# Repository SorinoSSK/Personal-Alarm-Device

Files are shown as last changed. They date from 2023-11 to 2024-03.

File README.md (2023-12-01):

# Introduction
This repository serves as a record and learning journey on hardware used for my capstone project. The objective of the project is to implement a small, affordable and unrestrictive IoT deviced that enables individuals to call for help in an emergency.

## PCB_Design_GSM_GPS
With the failure to find an appropriate module that carries both the functionality of GPS and GSM, I have decided to design a customised module using [SIM868](https://www.alibaba.com/product-detail/SIM868-Signal-Circuits-GSM-GPS-GNSS_1600272320629.html). SIM868 enables both GSM and GPS communication that is inline with the frequency band used in Singapore, however SIM868 is built for 2G communication and 2G communication is no longer used in Singapore. 

***Update: SIM868 is mostly no longer in production.***\
***SIM868 could not detect 3G or 4G network***

## Schematic_1
Upon searching for SIM868, I stumble across the module A9G and thus drew the schematic to be used for feasibility testing of our idea. A9G also uses GPRS protocol which still runs mostly on a [2G network](https://tinyurl.com/mwhuy22j). 

***Update: A9G could not detect 3G or 4G network***

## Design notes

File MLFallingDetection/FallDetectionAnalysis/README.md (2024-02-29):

# The analysis of falling data of accelerometer
Data are collected from the IMU, **LSM6DS3TR-C** installed within seeed XIAO nRf52840. The sum of square equation will be used on the 3 axis acceleration to obtain the resultant acceleration vector for the analysis. 

```
Norm = SQRT(ACCEL_X**2 + ACCEL_Y**2 + ACCEL_Z**2);
```

## Overview of data retrieved
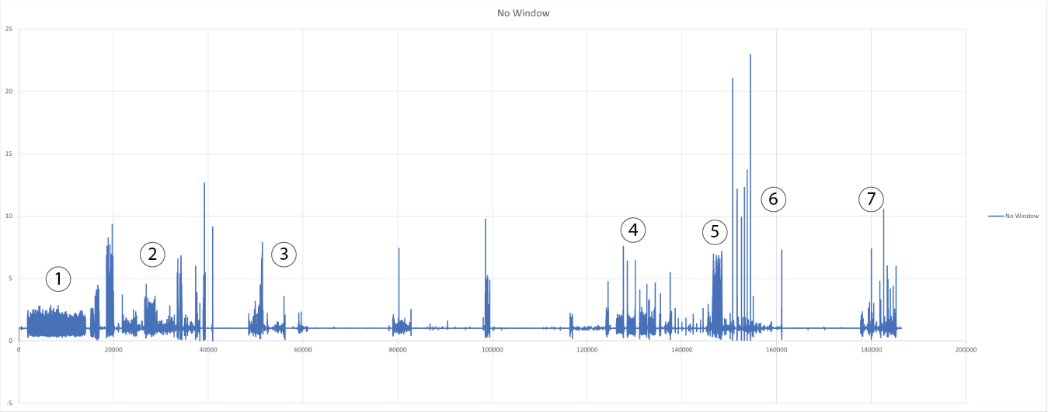
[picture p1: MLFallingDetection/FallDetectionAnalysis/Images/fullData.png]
Falling Data Full

**Legend**
1) Walking
2) Walking Up and Down Stairs
3) Dropping of IMU
4) Sitting and Standing up from plastic chair
5) Shaking of IMU
6) Falling from the chair
7) Fall forward

**Note**
1) The device designed to be used as a keychain, thus the device is placed in the back pocket of our pants during data collection.
2) The shaking of IMU is recorded with it held on the hand.

With that we will include the rate of change in acceleration, the second derivative in the rate of change in acceleration, and moving average of a window of 50 data point,

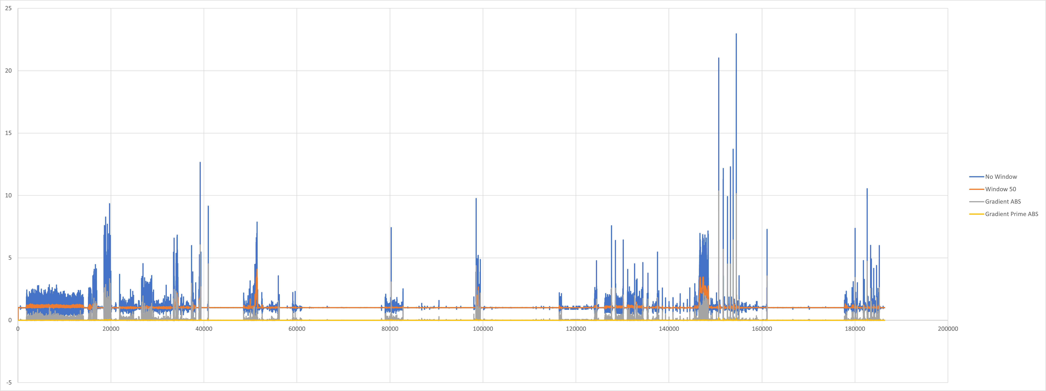
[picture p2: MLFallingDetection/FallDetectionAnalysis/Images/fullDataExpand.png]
Falling Data Full Expand


A few highest rate of change of acceleration will be recorded for analysis.

## Analysing **Walking**
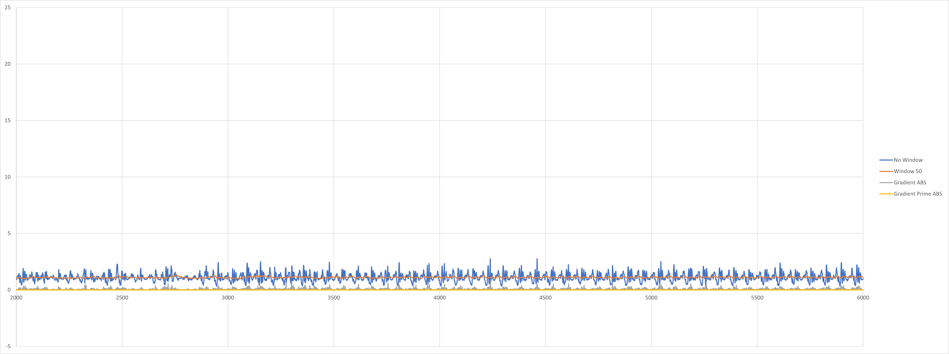
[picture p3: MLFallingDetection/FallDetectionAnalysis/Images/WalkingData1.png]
Walking Data 1

**Zooming in:**\
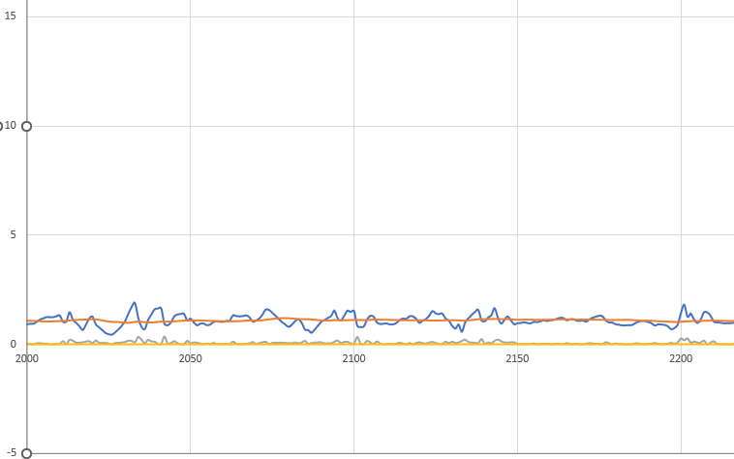
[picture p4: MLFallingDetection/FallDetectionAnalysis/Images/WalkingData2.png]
Walking Data 2

**Note**
1) Random points:

|point| Norm | f'(x) | f''(x) |
|-----|---|---|---|
|2101| 0.85 | 0.336068328 | 0.00305213  |
|2202| 1.25876924  | 0.271906121 | 0.003399633 |
|2325| 1.393448959 | 0.397809776 | 0.003501889 |

## Analysing **Stairs**
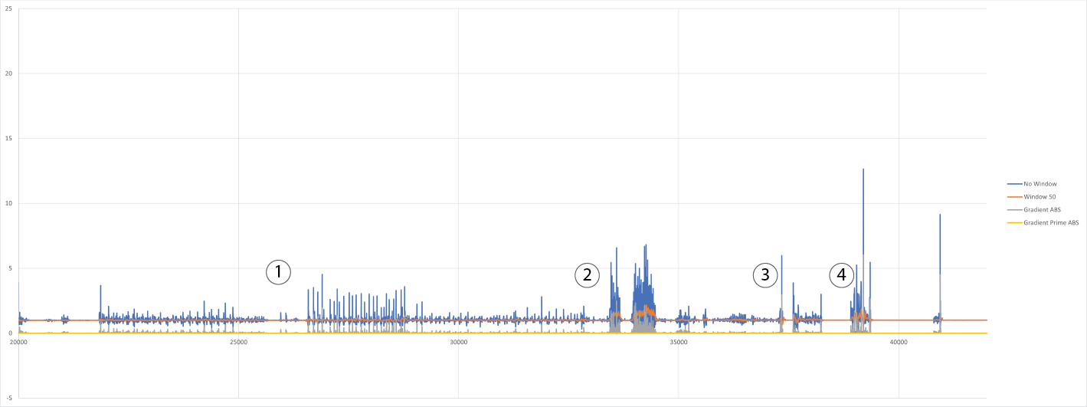
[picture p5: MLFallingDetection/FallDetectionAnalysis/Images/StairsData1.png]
Stairs Data 1

From the graph we could observe two different section where the norm acceleration for going up the stairs is way lower than going down the stairs. Thus, we will analyse the going down of stairs instead. 
**Legend**
1) Walking up then down the stairs
2) Limping up then down the stairs
3) Limping up then down the stairs (Other Leg)
4) Running up then down the stairs

### Walking up then down the stairs
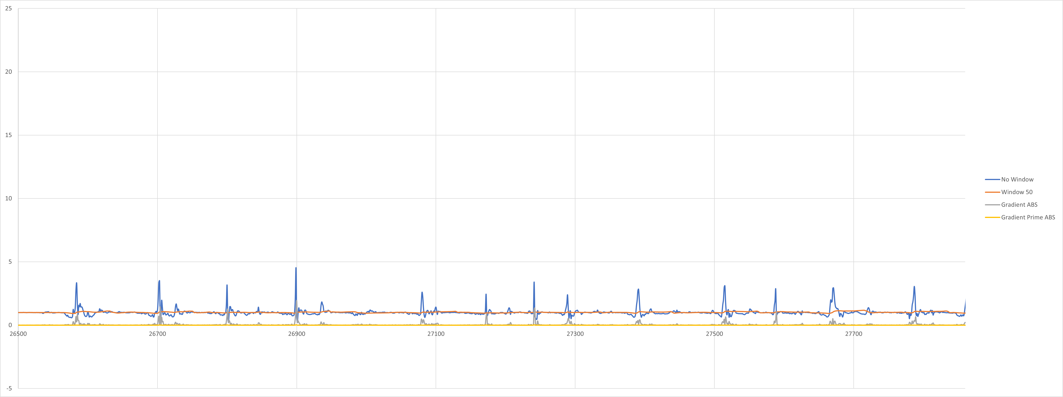
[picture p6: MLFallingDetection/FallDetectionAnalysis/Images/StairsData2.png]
Stairs Data 2

**Note**
|point| Norm | f'(x) | f''(x) |
|-----|---|---|---|
|26704| 0.595399026 | 1.453343034 | 0.015052862 |
|26900| 0.672978454 | 1.922880154 | 0.017114909 |
|27242| 0.904488806 | 0.175432193 | 0.00063385  |

### Limping up and then down the stairs
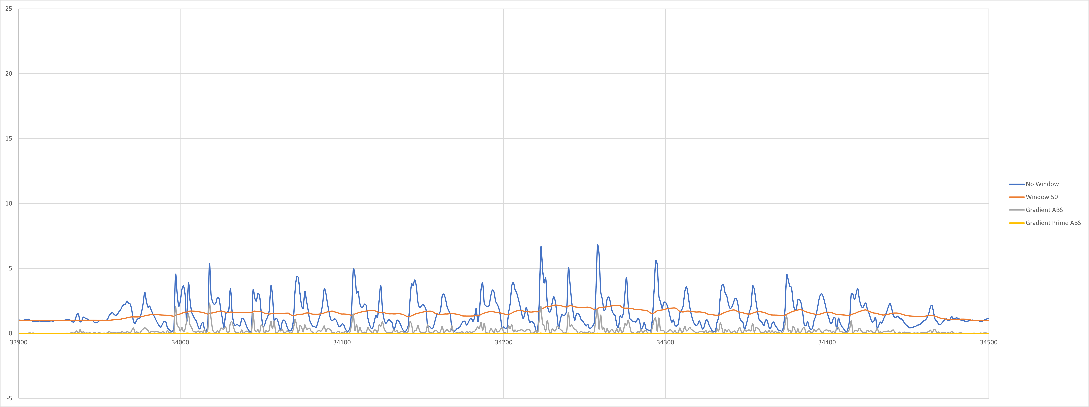
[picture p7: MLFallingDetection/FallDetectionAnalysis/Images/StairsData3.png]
Stairs Data 3

**Note**
|point| Norm | f'(x) | f''(x) |
|-----|---|---|---|
|34018| 5.320620265 | 2.319318931 | 0.034806461 |
|34223| 6.612503308 | 2.080303042 | 0.028609112 |
|34375| 4.503987123 | 1.345020579 | 0.015369838 |

### Limping up and then down the stairs (Other Leg)
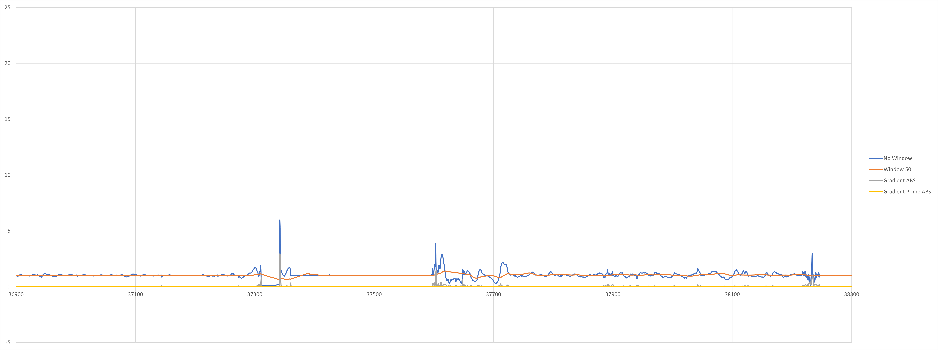
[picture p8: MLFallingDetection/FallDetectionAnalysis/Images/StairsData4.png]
Stairs Data 4

**Note**
|point| Norm | f'(x) | f''(x) |
|-----|---|---|---|
|37342| 5.97850316 | 2.89438325 | 0.05089264  |
|37604| 1.0177426  | 1.427956 | 0.014744675 |
|38234| 3.00627677 | 0.90062282 | 0.019383044 |

**Most Significant Detection**
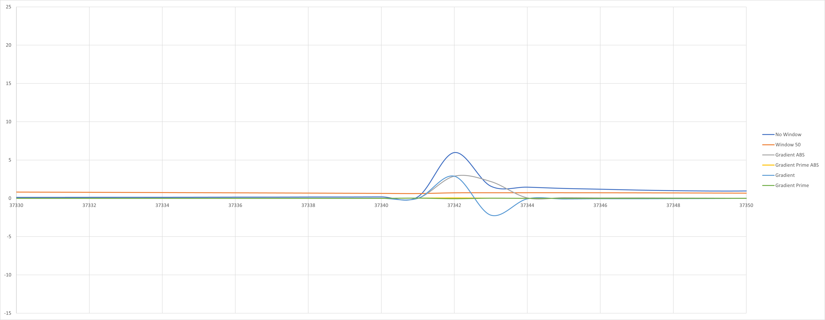
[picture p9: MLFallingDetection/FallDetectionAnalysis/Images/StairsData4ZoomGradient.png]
Stairs Data 4 Zoom


Gradient:  
Max = 2.894383249  
Min = -2.194880759  
*Max Gradient More Than 50 Mean, 0.720361147*

### Running up and then down the stairs
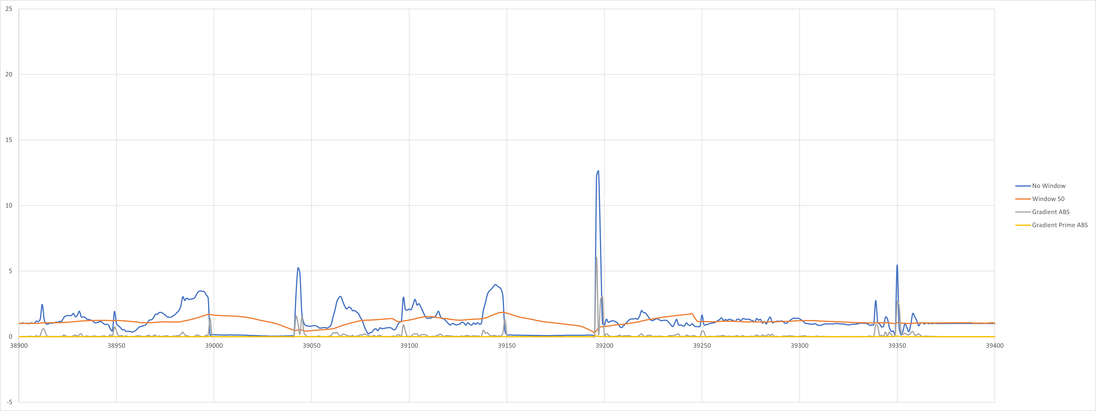
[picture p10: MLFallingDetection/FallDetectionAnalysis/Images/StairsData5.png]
Stairs Data 5

**Note**
|point| Norm | f'(x) | f''(x) |
|-----|---|---|---|
|39196| 12.2078213 | 6.03987939 | 0.058243241 |
|39199| 1.4169686  | 0.01073792 | 0.000376615 |
|39350| 5.46485133 | 2.64582312 | 0.050280346 |

**Most Significant Detection**
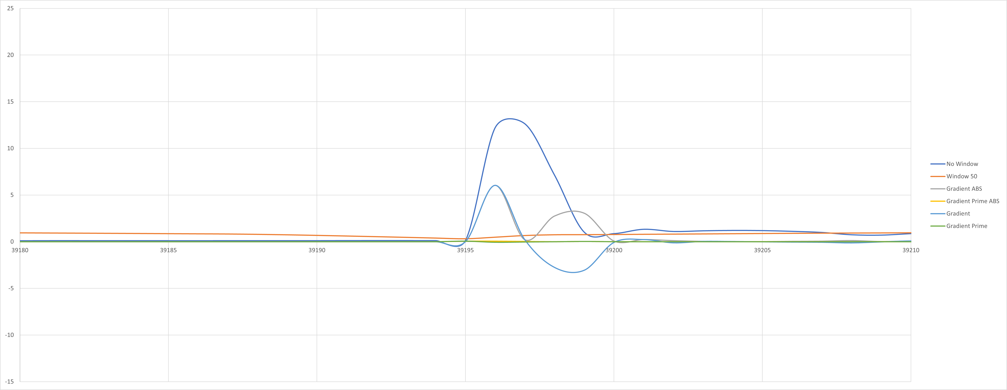
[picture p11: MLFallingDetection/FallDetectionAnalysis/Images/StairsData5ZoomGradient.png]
Stairs Data 5 Zoom


Gradient:  
Max = 1.713900863  
Min = -1.406512019  
*Max Gradient More Than 50 Mean, 0.485567491*

### Dropping of IMU
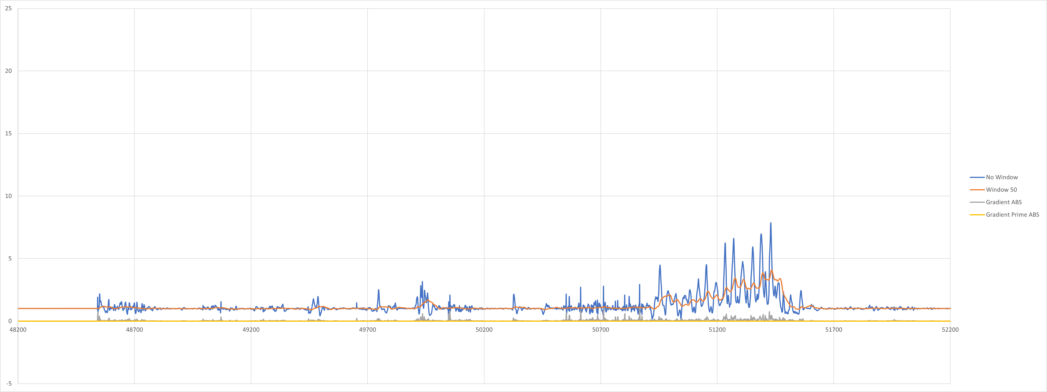
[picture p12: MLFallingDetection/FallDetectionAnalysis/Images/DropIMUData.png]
Drop IMU

**Note**
|point| Norm | f'(x) | f''(x) |
|-----|---|---|---|
|50867| 2.93165482 | 0.84010783 | 0.018871274 |
|51271| 6.60540688 | 0.07334979 | 0.003136808 |
|51429| 7.66756806 | 0.42955872 | 0.003312123 |

### Sitting and standing from plastic chair
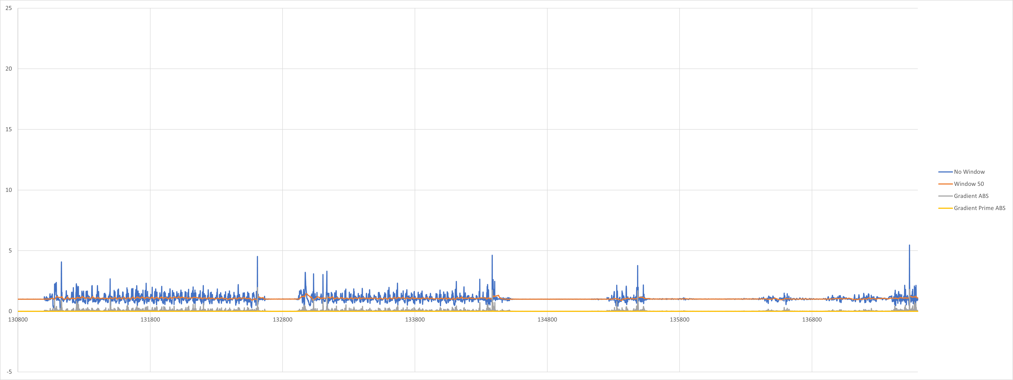
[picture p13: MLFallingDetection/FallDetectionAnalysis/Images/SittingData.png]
Sitting Standing

**Note**
|point| Norm | f'(x) | f''(x) |
|-----|---|---|---|
|124418| 1.3924439  | 1.67057441 | 0.016458247 |
|127650| 7.57681331 | 2.39403404 | 0.04951892  |
|128489| 6.39746043 | 2.56434075 | 0.050413023 |
|128490| 1.44353732 | 2.47696156 | 0.02131954  |

**Most Significant Detection**
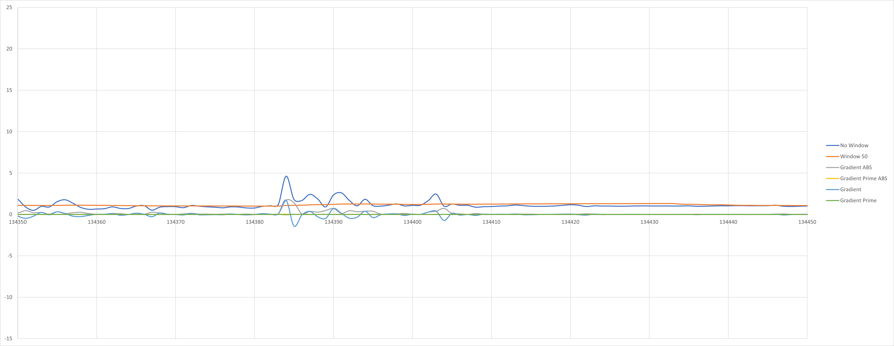
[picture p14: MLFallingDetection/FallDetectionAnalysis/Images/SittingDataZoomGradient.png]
Sitting Standing Zoom


### Shaking of IMU
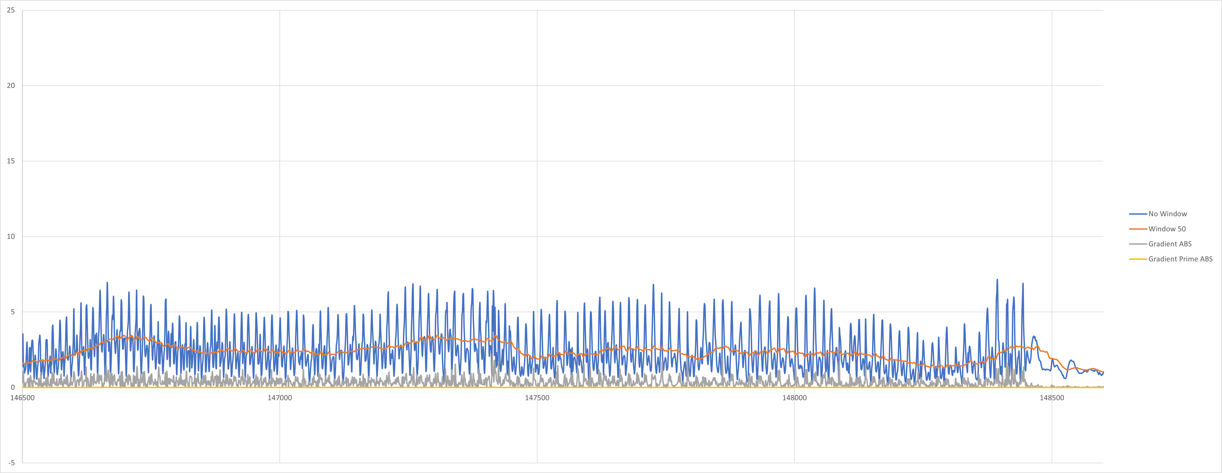
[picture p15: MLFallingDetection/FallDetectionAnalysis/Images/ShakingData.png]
Shaking of IMU

**Note**
|point| Norm | f'(x) | f''(x) |
|-----|---|---|---|
|147413| 5.33691859 | 2.18263525 | 0.02974069 |
|148087| 3.92880389 | 1.74343815 | 0.019434068|
|148412| 5.50270842 | 1.65809075 | 0.018426668|

**Most Significant Detection**
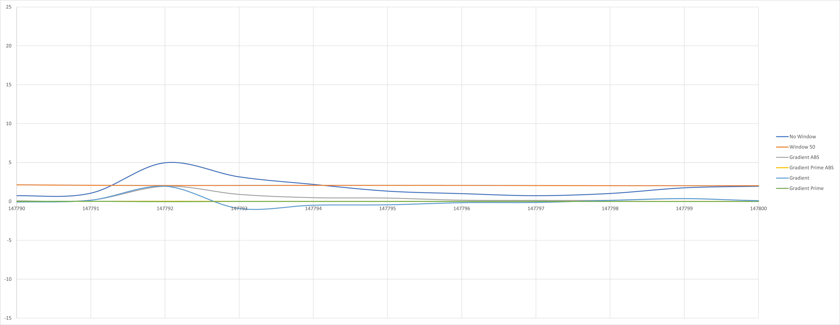
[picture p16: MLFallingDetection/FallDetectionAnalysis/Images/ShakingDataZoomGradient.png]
Shaking IMU Zoom


Gradient:  
Max = 1.713900863  
Min = -1.406512019  
*Max Gradient More Than 50 Mean, 1.084352*

### Falling
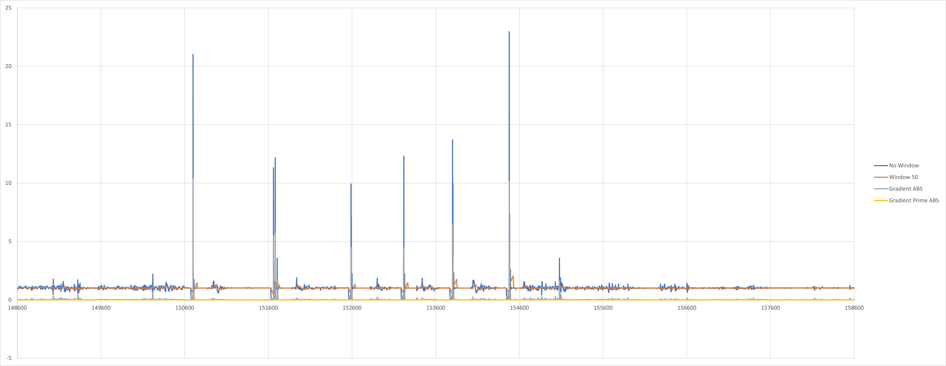
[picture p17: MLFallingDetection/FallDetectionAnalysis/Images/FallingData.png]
Falling

**Note**
|point| Norm | f'(x) | f''(x) |
|-----|---|---|---|
|150700| 21.0203187 | 10.2686019 | 0.19819152 |
|151661| 11.0312737 | 5.46538749 | 0.07213993 |
|151682| 12.1636426 | 5.63318495 | 0.108593481|
|152588| 9.91117047 | 4.42504366 | 0.082039699|
|153219| 12.2903051 | 3.57987967 | 0.080156318|
|153220| 3.41880096 | 4.43575208 | 0.037172477|
|153801| 13.5009852 | 6.39711601 | 0.090973936|
|154478| 22.5853692 | 10.1236572 | 0.140823507|

**Insignificant Detection**
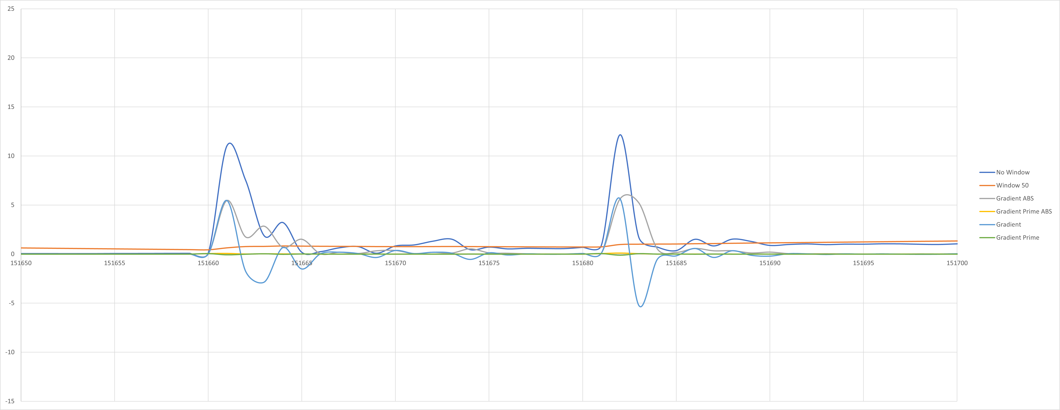
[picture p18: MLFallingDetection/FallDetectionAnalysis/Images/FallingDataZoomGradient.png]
Falling Zoom


Gradient:  
Max = 1.954421754  
Min = -0.48353773  
*Max Gradient Lower than 50 Mean*

### Falling Forward
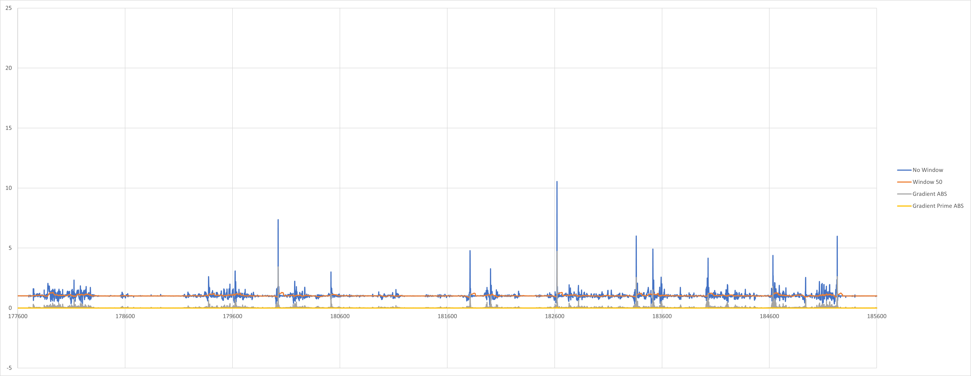
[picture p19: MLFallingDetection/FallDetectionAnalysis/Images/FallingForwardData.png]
Falling Forward

**Note**
|point| Norm | f'(x) | f''(x) |
|-----|---|---|---|
|180025| 7.3281495  | 3.38140316 | 0.053954091|
|181812| 4.75042103 | 1.17818295 | 0.014426057|
|182622| 10.5353643 | 3.69902825 | 0.083047814|
|182623| 1.323858 | 4.60575313 | 0.043626618|
|183360| 5.94348383 | 2.53134437 | 0.037461287|
|183515| 4.87521282 | 1.51486592 | 0.022030153|
|184633| 4.35516934 | 1.79035089 | 0.026907707|
|185232| 5.98194784 | 2.56913272 | 0.046908972|

**Insignificant Detection**
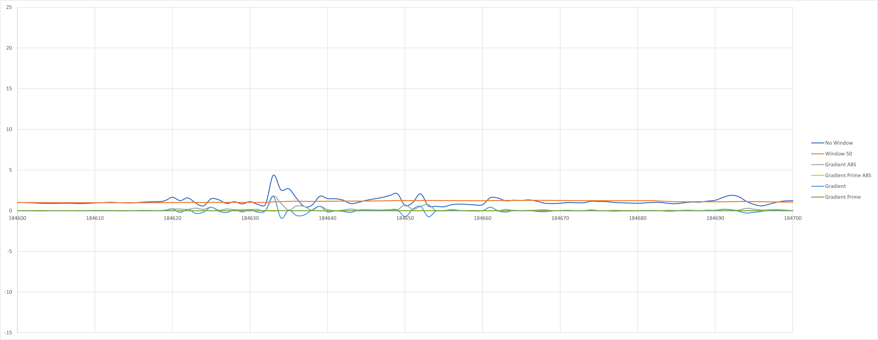
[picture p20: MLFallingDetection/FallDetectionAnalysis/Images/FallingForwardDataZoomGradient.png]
Falling Zoom Forward


### Summaries Data
|Type|point| Norm | f'(x) | f''(x) |
|----|-----|---|---|---|
|1|2101| 0.85 | 0.336068328 | 0.00305213  |
|1|2202| 1.25876924  | 0.271906121 | 0.003399633 |
|1|2325| 1.393448959 | 0.397809776 | 0.003501889 |
|2.1|26704| 0.595399026 | 1.453343034 | 0.015052862 |
|2.1|26900| 0.672978454 | 1.922880154 | 0.017114909 |
|2.1|27242| 0.904488806 | 0.175432193 | 0.00063385  |
|2.2|34018| 5.320620265 | 2.319318931 | 0.034806461 |
|2.2|34223| 6.612503308 | 2.080303042 | 0.028609112 |
|2.2|34375| 4.503987123 | 1.345020579 | 0.015369838 |
|2.3|37342| 5.97850316 | 2.89438325 | 0.05089264  |
|2.3|37604| 1.0177426  | 1.427956 | 0.014744675 |
|2.3|38234| 3.00627677 | 0.90062282 | 0.019383044 |
|2.4|39196| 12.2078213 | 6.03987939 | 0.058243241 |
|2.4|39199| 1.4169686  | 0.01073792 | 0.000376615 |
|2.4|39350| 5.46485133 | 2.64582312 | 0.050280346 |
|3|50867| 2.93165482 | 0.84010783 | 0.018871274 |
|3|51271| 6.60540688 | 0.07334979 | 0.003136808 |
|3|51429| 7.66756806 | 0.42955872 | 0.003312123 |
|4|124418| 1.3924439  | 1.67057441 | 0.016458247 |
|4|127650| 7.57681331 | 2.39403404 | 0.04951892  |
|4|128489| 6.39746043 | 2.56434075 | 0.050413023 |
|4|128490| 1.44353732 | 2.47696156 | 0.02131954  |
|5|147413| 5.33691859 | 2.18263525 | 0.02974069 |
|5|148087| 3.92880389 | 1.74343815 | 0.019434068|
|5|148412| 5.50270842 | 1.65809075 | 0.018426668|
|6|150700| 21.0203187 | 10.2686019 | 0.19819152 |
|6|151661| 11.0312737 | 5.46538749 | 0.07213993 |
|6|151682| 12.1636426 | 5.63318495 | 0.108593481|
|6|152588| 9.91117047 | 4.42504366 | 0.082039699|
|6|153219| 12.2903051 | 3.57987967 | 0.080156318|
|6|153220| 3.41880096 | 4.43575208 | 0.037172477|
|6|153801| 13.5009852 | 6.39711601 | 0.090973936|
|6|154478| 22.5853692 | 10.1236572 | 0.140823507|
|7|180025| 7.3281495  | 3.38140316 | 0.053954091|
|7|181812| 4.75042103 | 1.17818295 | 0.014426057|
|7|182622| 10.5353643 | 3.69902825 | 0.083047814|
|7|182623| 1.323858 | 4.60575313 | 0.043626618|
|7|183360| 5.94348383 | 2.53134437 | 0.037461287|
|7|183515| 4.87521282 | 1.51486592 | 0.022030153|
|7|184633| 4.35516934 | 1.79035089 | 0.026907707|
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

From the above data we can denote the following

|Non-Falling|Norm|f'(x)|f''(x)|
|---|----|-----|---|
|Min|0.595399026|0.01073792|0.000376615|
|Max|12.2078213|6.03987939|0.058243241|

|Falling|Norm|f'(x)|f''(x)|
|---|----|-----|---|
|Min|1.323858|1.17818295|0.014426057|
|Max|22.5853692|10.2686019|0.19819152|

From the data we can assume the following:
1) If f''(x) is > 0.06, we could say that a fall occur.
2) For f'(x) > 1.178, we will need a second verification.
3) For f(x) > 1.323, we will need a second verificaiton.

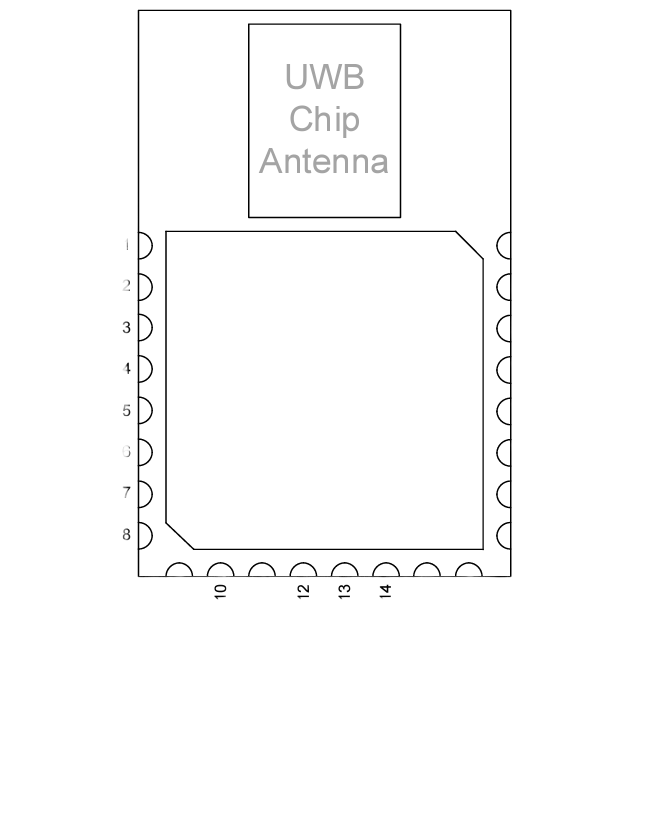
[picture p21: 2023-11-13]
Device Design/Schematic_1/Image/DWM1000_nobg.png

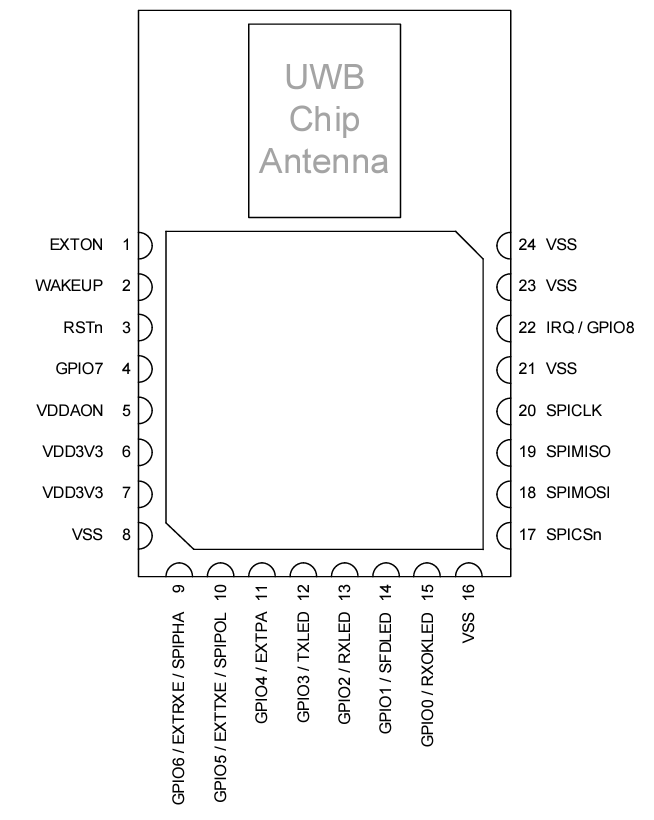
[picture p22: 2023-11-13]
Device Design/Schematic_1/Image/DWM1000.png

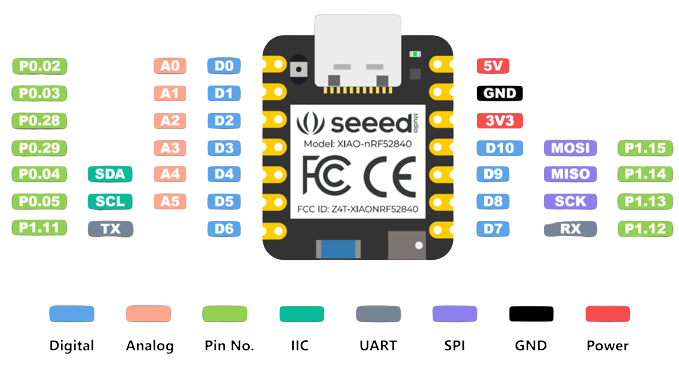
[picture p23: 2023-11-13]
Device Design/Schematic_1/Image/seeed_Xiao_nobg.png

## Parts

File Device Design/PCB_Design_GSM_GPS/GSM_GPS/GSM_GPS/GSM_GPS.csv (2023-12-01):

Source: | D:\[01] Laptop Files\[02] GitFolder\Capstone-2023\PCB_Design_GSM_GPS\GSM_GPS\GSM_GPS.kicad_sch
Date: | 13/11/2023 8:51
Tool: | Eeschema 7.0.8
Generator: | C:\Program Files\KiCad\7.0\bin\scripting\plugins/bom_csv_grouped_by_value.py
Component Count: | 61
Collated Components:
Item | Qty | Reference(s) | Value | LibPart | Footprint | Datasheet | DNP | Availability | Check_prices | Description | MANUFACTURER | MAXIMUM_PACKAGE_HEIGHT | MF | MP | PARTREV | Package | Price | Purchase-URL | STANDARD | SnapEDA_Link
1 | 2 | C1, C4 | 100uF | Device:C_Small | Capacitor_SMD:C_0805_2012Metric | ~
2 | 3 | C2, C3, C14 | 330uF | Device:C_Polarized_Small | Capacitor_SMD:CP_Elec_8x10.5 | ~
3 | 1 | C5 | 33pF | Device:C_Small | Capacitor_SMD:C_0201_0603Metric | ~
4 | 1 | C6 | 10pF | Device:C_Small | Capacitor_SMD:C_0402_1005Metric | ~
5 | 3 | C7, C8, C9 | 22pF | Device:C_Small | Capacitor_SMD:C_0402_1005Metric | ~
6 | 2 | C10, C15 | 0.1uF | Device:C_Small | Capacitor_SMD:C_0201_0603Metric | ~
7 | 1 | C11 | 0.5pF | Device:C_Small | Capacitor_SMD:C_0201_0603Metric | ~
8 | 1 | C12 | 100uF | Device:C_Polarized_Small | Capacitor_SMD:CP_Elec_6.3x5.4 | ~
9 | 1 | C13 | 1uF | Device:C_Small | Capacitor_SMD:C_0201_0603Metric | ~
10 | 2 | D2, D3 | LED | Device:LED | LED_SMD:LED_0201_0603Metric_Pad0.64x0.40mm_HandSolder | ~
11 | 1 | D4 | ESDA6V1-5SC6 | Power_Protection:ESDA6V1-5SC6 | Package_TO_SOT_SMD:SOT-23-6 | www.st.com/resource/en/datasheet/esda6v1-5sc6.pdf
12 | 1 | D5 | 5.1V | Device:D_Zener | Diode_SMD:D_0201_0603Metric | ~
13 | 1 | E1 | YC0003AA | YC0003AA:YC0003AA | YC0003AA:XCVR_YC0003AA |  |  | In Stock | https://www.snapeda.com/parts/YC0003AA/Quectel/view-part/?ref=eda | Frequency band: 698960MHz, 16952200MHz, 23002700MHz; Peak efficiency: 79%; Dimensions: 40mm 7mm 3mm; SMD supplied tape and reel; RoHS and REACH compliant. | Quectel | 3.3mm | Quectel Wireless Solutions Co., Ltd | YC0003AA | 3 | None | None | https://www.snapeda.com/api/url_track_click_mouser/?unipart_id=5161832&manufacturer=Quectel Wireless Solutions Co., Ltd&part_name=YC0003AA&search_term=None | Manufacturer Recommendations | https://www.snapeda.com/parts/YC0003AA/Quectel/view-part/?ref=snap
14 | 1 | E2 | ACAG0301-1575-T | ACAG0301-1575-T:ACAG0301-1575-T | ACAG0301-1575-T:ANT_ACAG0301-1575-T |  |  | In Stock | https://www.snapeda.com/parts/ACAG0301-1575-T/Abracon+LLC/view-part/?ref=eda | MULTIBAND GNSS CHIP ANT SMD | Abracon LLC | 0.7 mm | Abracon LLC | ACAG0301-1575-T | 06.21.2018 | SMD Abracon LLC | None | https://www.snapeda.com/api/url_track_click_mouser/?unipart_id=3077605&manufacturer=Abracon LLC&part_name=ACAG0301-1575-T&search_term=None | Manufacturer Recommendations | https://www.snapeda.com/parts/ACAG0301-1575-T/Abracon+LLC/view-part/?ref=snap
15 | 1 | J1 | SIM8051-6-0-14-00-X-REVD | SIM8051-6-0-14-00-X-REVD:SIM8051-6-0-14-00-X-REVD | SIM8051-6-0-14-00-X-REVD:GCT_SIM8051-6-0-14-00-X-REVD |  |  | In Stock | https://www.snapeda.com/parts/SIM8051-6-0-14-00-A/Global+Connector+Technology/view-part/?ref=eda | 6 Position Card Connector NANO SIM Surface Mount, Right Angle Gold | GCT |  | Global Connector Technology | SIM8051-6-0-14-00-A |  | None | None |  |  | https://www.snapeda.com/parts/SIM8051-6-0-14-00-A/Global+Connector+Technology/view-part/?ref=snap
16 | 8 | J2, J3, J5, J6, J8, J9, J10, J11 | Conn_01x03_Pin | Connector:Conn_01x03_Pin | Connector_Molex:Molex_SPOX_5267-03A_1x03_P2.50mm_Vertical | ~
17 | 9 | J4, J12, J13, J14, J15, J16, J17, J18, J19 | Conn_01x04_Pin | Connector:Conn_01x04_Pin | Connector_Molex:Molex_SPOX_5267-04A_1x04_P2.50mm_Vertical | ~
18 | 3 | J7, J20, J21 | Conn_01x02_Pin | Connector:Conn_01x02_Pin | Connector_Molex:Molex_SPOX_5267-02A_1x02_P2.50mm_Vertical | ~
19 | 1 | L1 | 3.3nH | Device:L | Inductor_SMD:L_0402_1005Metric | ~
20 | 1 | L2 | 6.8nH | Device:L | Inductor_SMD:L_0201_0603Metric | ~
21 | 1 | L3 | 2.4nH | Device:L | Inductor_SMD:L_0402_1005Metric | ~
22 | 1 | L4 | 5.6nH | Device:L | Inductor_SMD:L_0201_0603Metric | ~
23 | 1 | Q1 | 2N3904 | Transistor_BJT:2N3904 | Package_TO_SOT_THT:TO-92_Inline | https://www.onsemi.com/pub/Collateral/2N3903-D.PDF
24 | 3 | R1, R2, R3 | 22 | Device:R | Resistor_SMD:R_0201_0603Metric | ~
25 | 4 | R4, R5, R6, R7 | 4.7k | Device:R | Resistor_SMD:R_0201_0603Metric | ~
26 | 1 | R8 | 10k | Device:R | Resistor_SMD:R_0201_0603Metric | ~
27 | 1 | R9 | 100k | Device:R | Resistor_SMD:R_0201_0603Metric | ~
28 | 1 | R10 | 43k | Device:R | Resistor_SMD:R_0805_2012Metric | ~
29 | 1 | R11 | 470k | Device:R | Resistor_SMD:R_0201_0603Metric | ~
30 | 1 | U1 | SIM868 | SIM868:SIM868 | SIM868:XCVR_SIM868 |  |  | Not in stock | https://www.snapeda.com/parts/SIM868/MikroElektronika/view-part/?ref=eda | SIM868 GNSS, GSM RF mikroBUS™ Click™ Platform Evaluation Expansion Board | SimCom |  | MikroElektronika | SIM868 |  | None | None |  |  | https://www.snapeda.com/parts/SIM868/MikroElektronika/view-part/?ref=snap
31 | 1 | U2 | SeeeduinoXIAO nRF52840 Sense | Seeeduino XIAO:SeeeduinoXIAO | Seeed Studio XIAO Series Library:XIAO-nRF52840-Sense-14P-2.54-21X17.8MM
32 | 1 | U3 | MIC29302AWD | Regulator_Linear:MIC29302AWD | Package_TO_SOT_SMD:TO-252-5_TabPin3 | https://ww1.microchip.com/downloads/aemDocuments/documents/OTH/ProductDocuments/DataSheets/20005897B.pdf

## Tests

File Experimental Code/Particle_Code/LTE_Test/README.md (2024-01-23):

# LTE_Test

This firmware project was created using [Particle Developer Tools](https://www.particle.io/developer-tools/) and is compatible with all [Particle Devices](https://www.particle.io/devices/).

Feel free to replace this README.md file with your own content, or keep it for reference.

## Table of Contents
- [Introduction](#introduction)
- [Prerequisites To Use This Template](#prerequisites-to-use-this-repository)
- [Getting Started](#getting-started)
- [Particle Firmware At A Glance](#particle-firmware-at-a-glance)
  - [Logging](#logging)
  - [Setup and Loop](#setup-and-loop)
  - [Delays and Timing](#delays-and-timing)
  - [Testing and Debugging](#testing-and-debugging)
  - [GitHub Actions (CI/CD)](#github-actions-cicd)
  - [OTA](#ota)
- [Support and Feedback](#support-and-feedback)
- [Version](#version)

## Introduction

For an in-depth understanding of this project template, please refer to our [documentation](https://docs.particle.io/firmware/best-practices/firmware-template/).

## Prerequisites To Use This Repository

To use this software/firmware on a device, you'll need:

- A [Particle Device](https://www.particle.io/devices/).
- Windows/Mac/Linux for building the software and flashing it to a device.
- [Particle Development Tools](https://docs.particle.io/getting-started/developer-tools/developer-tools/) installed and set up on your computer.
- Optionally, a nice cup of tea (and perhaps a biscuit).

## Getting Started

1. While not essential, we recommend running the [device setup process](https://setup.particle.io/) on your Particle device first. This ensures your device's firmware is up-to-date and you have a solid baseline to start from.

2. If you haven't already, open this project in Visual Studio Code (File -> Open Folder). Then [compile and flash](https://docs.particle.io/getting-started/developer-tools/workbench/#cloud-build-and-flash) your device. Ensure your device's USB port is connected to your computer.

3. Verify the device's operation by monitoring its logging output:
    - In Visual Studio Code with the Particle Plugin, open the [command palette](https://docs.particle.io/getting-started/developer-tools/workbench/#particle-commands) and choose "Particle: Serial Monitor".
    - Or, using the Particle CLI, execute:
    ```
    particle serial monitor --follow
    ```

4. Uncomment the code at the bottom of the cpp file in your src directory to publish to the Particle Cloud! Login to console.particle.io to view your devices events in real time.

5. Customize this project! For firmware details, see [Particle firmware](https://docs.particle.io/reference/device-os/api/introduction/getting-started/). For information on the project's directory structure, visit [this link](https://docs.particle.io/firmware/best-practices/firmware-template/#project-overview).

## Particle Firmware At A Glance

### Logging

The firmware includes a [logging library](https://docs.particle.io/reference/device-os/api/logging/logger-class/). You can display messages at different levels and filter them:

```
Log.trace("This is trace message");
Log.info("This is info message");
Log.warn("This is warn message");
Log.error("This is error message");
```

### Setup and Loop

Particle projects originate from the Wiring/Processing framework, which is based on C++. Typically, one-time setup functions are placed in `setup()`, and the main application runs from the `loop()` function.

For advanced scenarios, explore our [threading support](https://docs.particle.io/firmware/software-design/threading-explainer/).

### Delays and Timing

By default, the setup() and loop() functions are blocking whilst they run, meaning that if you put in a delay, your entire application will wait for that delay to finish before anything else can run. 

For techniques that allow you to run multiple tasks in parallel without creating threads, checkout the code example [here](https://docs.particle.io/firmware/best-practices/firmware-template/).

(Note: Although using `delay()` isn't recommended for best practices, it's acceptable for testing.)

### Testing and Debugging

For firmware testing and debugging guidance, check [this documentation](https://docs.particle.io/troubleshooting/guides/build-tools-troubleshooting/debugging-firmware-builds/).

### GitHub Actions (CI/CD)

This project provides a YAML file for GitHub, automating firmware compilation whenever changes are pushed. More details on [Particle GitHub Actions](https://docs.particle.io/firmware/best-practices/github-actions/) are available.

### OTA

To learn how to utilize Particle's OTA service for device updates, consult [this documentation](https://docs.particle.io/getting-started/cloud/ota-updates/).

Test OTA with the 'Particle: Cloud Flash' command in Visual Studio Code or the CLI command 'particle flash'!

This firmware supports binary assets in OTA packages, allowing the inclusion of audio, images, configurations, and external microcontroller firmware. More details are [here](https://docs.particle.io/reference/device-os/api/asset-ota/asset-ota/).

## Support and Feedback

For support or feedback on this template or any Particle products, please join our [community](https://community.particle.io)!

## Version

Template version 1.0.2

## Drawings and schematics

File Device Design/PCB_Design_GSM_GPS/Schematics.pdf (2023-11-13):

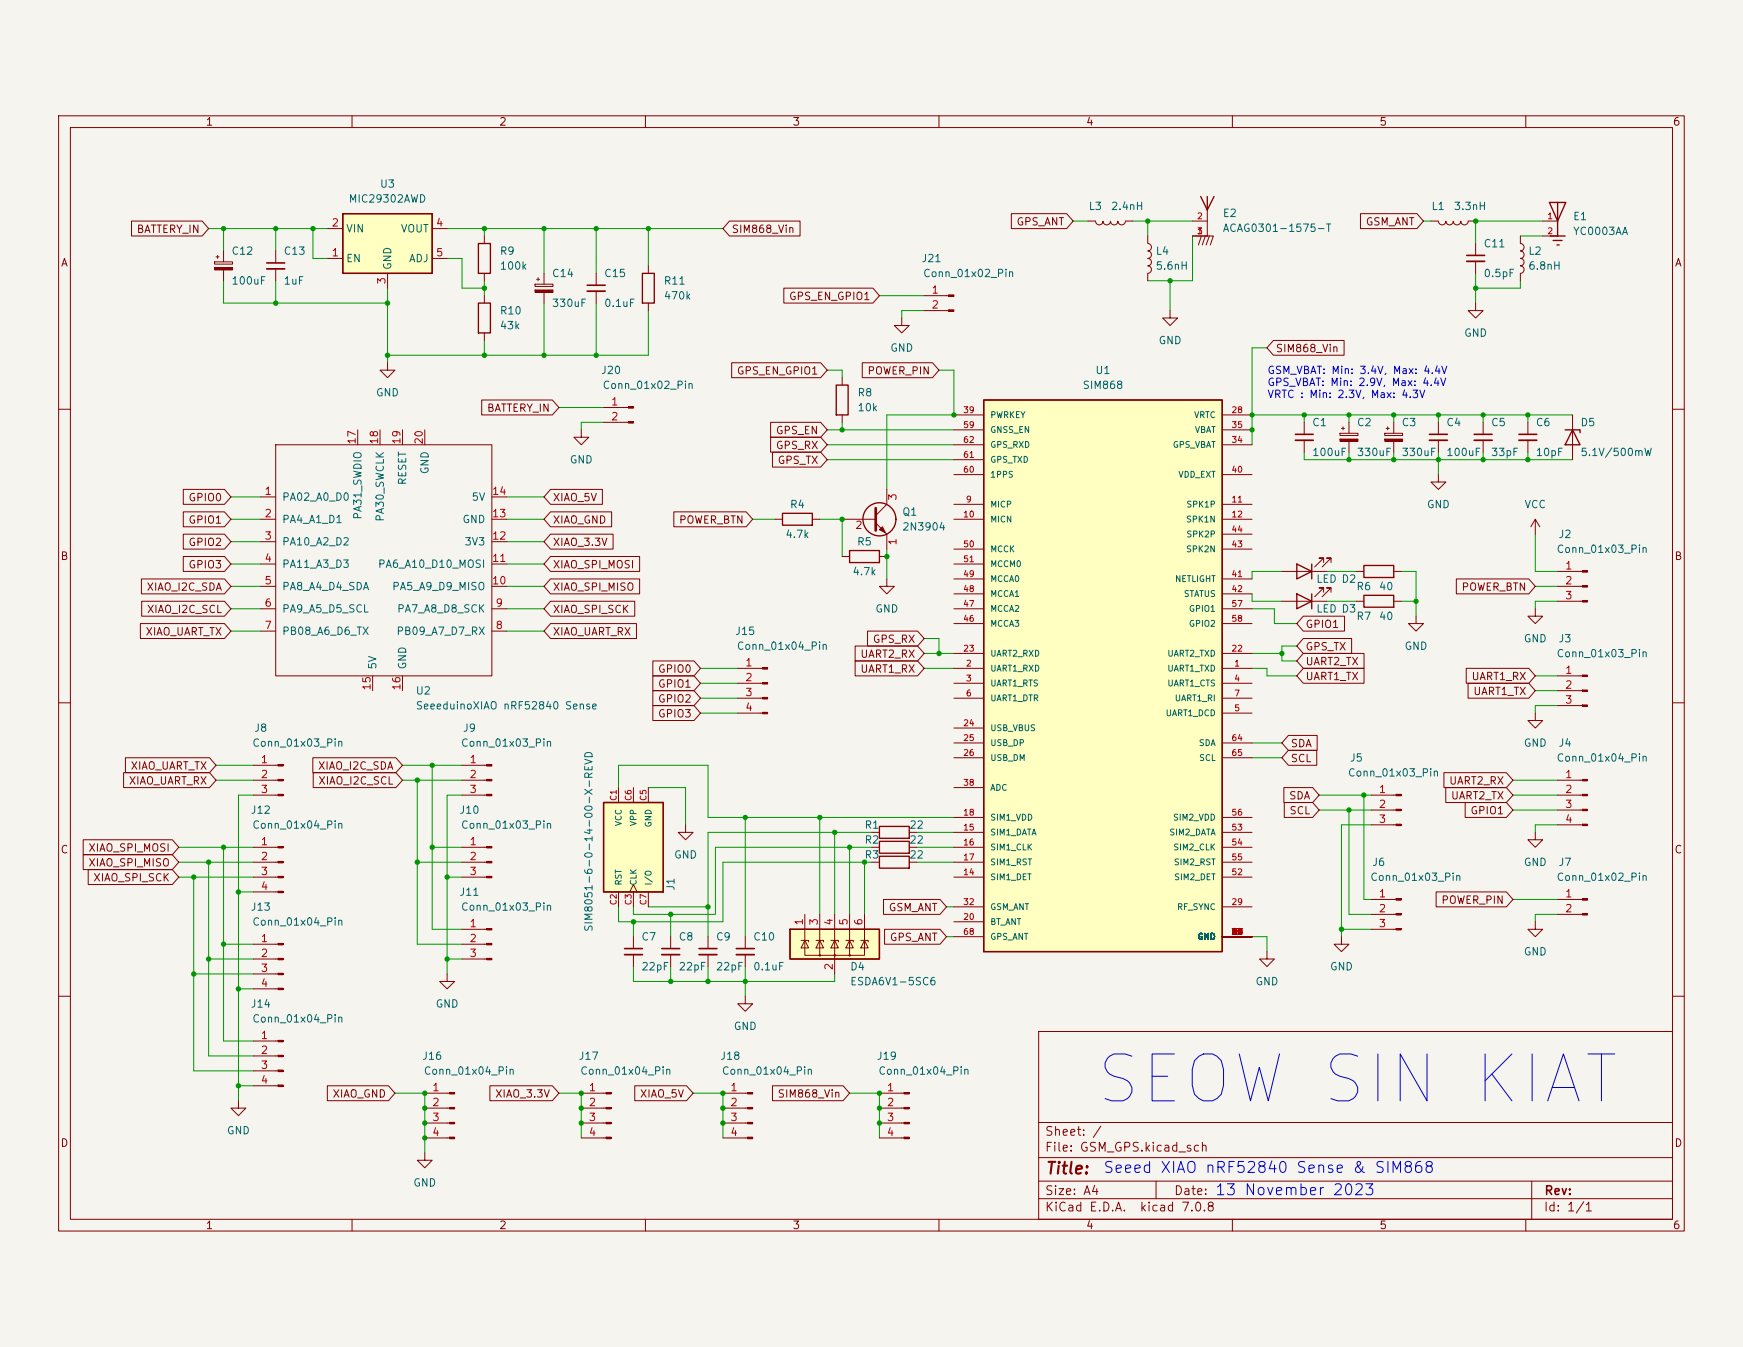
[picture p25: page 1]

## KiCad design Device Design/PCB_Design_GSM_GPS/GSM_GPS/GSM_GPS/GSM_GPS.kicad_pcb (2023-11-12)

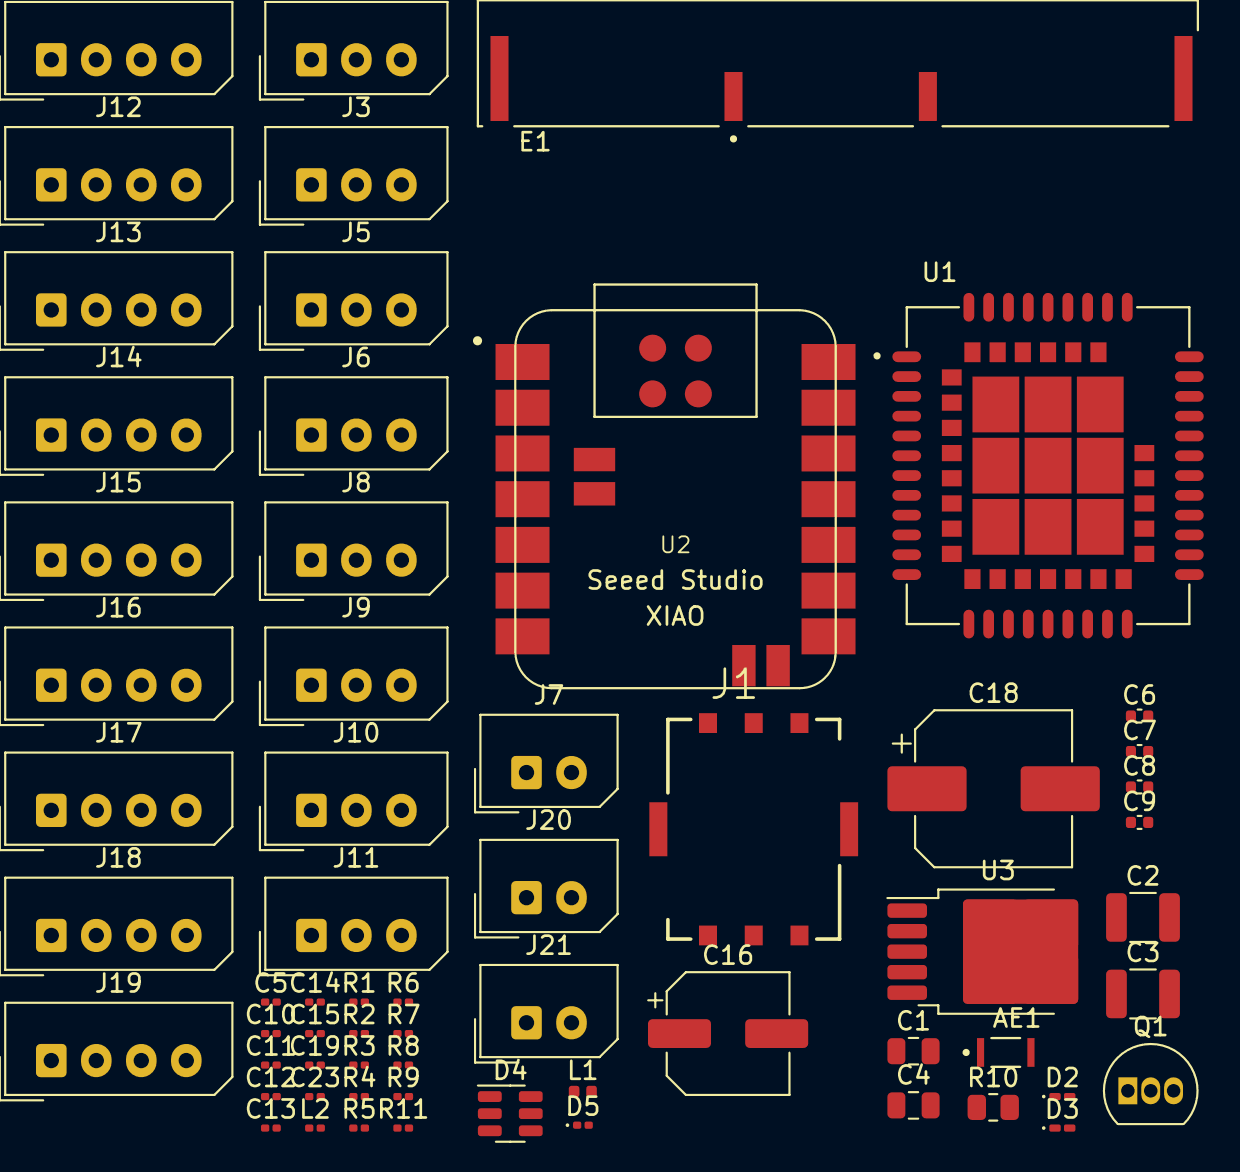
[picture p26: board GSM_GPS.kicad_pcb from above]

Board: 2 copper layers, 63 parts (0 on the bottom side), 45 nets, no tracks yet.

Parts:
AE1: GGBLA.01.A; XCVR_GGBLA.01.A
C1, C4: 100uF; C_0805_2012Metric
C2, C3: 330uF; C_1210_3225Metric
C5: 33pF; C_0201_0603Metric
C6: 10pF; C_0402_1005Metric
C7, C8, C9: 22pF; C_0402_1005Metric
C10, C19: 0.1uF; C_0201_0603Metric
C11, C14: 0.5pF; C_0201_0603Metric
C12: 1uF; C_0201_0603Metric
C13: 0.8pF; C_0201_0603Metric
C15: 22pF; C_0201_0603Metric
C16: 100uF; CP_Elec_6.3x7.7
C18: 330uF; CP_Elec_8x10.5
C23: 2.7pF; C_0201_0603Metric
D2, D3: LED; LED_0201_0603Metric_Pad0.64x0.40mm_HandSolder
D4: ESDA6V1-5SC6; SOT-23-6
D5: 5.1V; D_0201_0603Metric
E1: YC0003AA; XCVR_YC0003AA
J1: SIM8051-6-0-14-00-X-REVD; GCT_SIM8051-6-0-14-00-X-REVD
J2, J3, J5, J6, J8, J9, J10, J11: Conn_01x03_Pin; Molex_SPOX_5267-03A_1x03_P2.50mm_Vertical
J4, J12, J13, J14, J15, J16, J17, J18, J19: Conn_01x04_Pin; Molex_SPOX_5267-04A_1x04_P2.50mm_Vertical
J7, J20, J21: Conn_01x02_Pin; Molex_SPOX_5267-02A_1x02_P2.50mm_Vertical
L1: 3.3nH; L_0402_1005Metric
L2: 6.8nH; L_0201_0603Metric
Q1: 2N3904; TO-92_Inline
R1, R2, R3: 22; R_0201_0603Metric
R4: 100k; R_0201_0603Metric
R5, R6, R7, R8: 4.7k; R_0201_0603Metric
R9: 10k; R_0201_0603Metric
R10: 43k; R_0805_2012Metric
R11: 470k; R_0201_0603Metric
U1: SIM868; XCVR_SIM868
U2: SeeeduinoXIAO nRF52840 Sense; XIAO-nRF52840-Sense-14P-2.54-21X17.8MM
U3: MIC29302AWD; TO-252-5_TabPin3

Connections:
BATTERY_IN: C12.1, C16.1, J20.1, U3.1 (EN), U3.2 (VIN)
GPIO0: J15.1, U2.1 (PA02_A0_D0)
GPIO1: J4.3, J15.2, U1.57 (GPIO1), U2.2 (PA4_A1_D1)
GPIO2: J15.3, U2.3 (PA10_A2_D2)
GPIO3: J15.4, U2.4 (PA11_A3_D3)
GPS_ANT: C23.2, U1.68 (GPS_ANT)
GPS_EN: R9.2, U1.59 (GNSS_EN)
GPS_EN_GPIO1: J21.1, R9.1
GPS_RX: J4.1, U1.23 (UART2_RXD), U1.62 (GPS_RXD)
GPS_TX: J4.2, U1.22 (UART2_TXD), U1.61 (GPS_TXD)
GSM_ANT: L1.2, U1.32 (GSM_ANT)
unnamed: C14.1, C15.1
unnamed: AE1.1 (RF_Feed), C13.1, C14.2, C23.1
unnamed: C11.1, E1.1, L1.1
unnamed: D2.2 (A), U1.41 (NETLIGHT)
unnamed: D2.1 (K), R7.1
unnamed: D3.2 (A), U1.42 (STATUS)
unnamed: D3.1 (K), R8.1
unnamed: C10.1, D4.3 (IO2), J1.C1 (VCC), U1.18 (SIM1_VDD)
unnamed: C9.1, D4.4 (IO3), J1.C7 (I/O), R1.1
unnamed: C8.1, D4.5 (IO4), J1.C3 (CLK), R2.1
unnamed: C7.1, D4.6 (IO5), J1.C2 (RST), R3.1
unnamed: E1.2, L2.1
unnamed: Q1.2 (B), R5.2, R6.1
unnamed: R2.2, U1.16 (SIM1_CLK)
unnamed: R1.2, U1.15 (SIM1_DATA)
unnamed: R3.2, U1.17 (SIM1_RST)
unnamed: R4.2, R10.1, U3.5 (ADJ)
POWER_BTN: J2.2, R5.1
POWER_PIN: J7.1, Q1.3 (C), U1.39 (PWRKEY)
SCL: J5.2, J6.2, U1.65 (SCL)
SDA: J5.1, J6.1, U1.64 (SDA)
SIM868_Vin: C1.1, C2.1, C3.1, C4.1, C5.1, C6.1, C18.1, C19.1, D5.1 (K), J19.1, J19.2, J19.3, J19.4, R4.1, R11.1, U1.28 (VRTC), U1.34 (GPS_VBAT), U1.35 (VBAT), U3.4 (VOUT)
UART1_RX: J3.1, U1.2 (UART1_RXD)
UART1_TX: J3.2, U1.1 (UART1_TXD)
XIAO_3.3V: J17.1, J17.2, J17.3, J17.4, U2.12 (3V3)
XIAO_5V: J18.1, J18.2, J18.3, J18.4, U2.14 (5V)
XIAO_GND: AE1.2 (gnd), C1.2, C2.2, C3.2, C4.2, C5.2, C6.2, C7.2, C8.2, C9.2, C10.2, C11.2, C12.2, C13.2, C15.2, C16.2, C18.2, C19.2, D4.2 (GND), D5.2 (A), J1.C5 (GND), J2.3, J3.3, J4.4, J5.3, J6.3, J7.2, J8.3, J9.3, J10.3, J11.3, J12.4, J13.4, J14.4, J16.1, J16.2, J16.3, J16.4, J20.2, J21.2, L2.2, Q1.1 (E), R6.2, R7.2, R8.2, R10.2, R11.2, U1.8 (GND), U1.13 (GND), U1.19 (GND), U1.21 (GND), U1.27 (GND), U1.30 (GND), U1.31 (GND), U1.33 (GND), U1.36 (GND), U1.37 (GND), U1.45 (GND), U1.63 (GND), U1.66 (GND), U1.67 (GND), U1.69 (GND), U1.70 (GND), U1.71 (GND), U1.72 (GND), U1.73 (GND), U1.74 (GND), U1.75 (GND), U1.76 (GND), U1.77 (GND), U2.13 (GND), U3.3 (GND)
XIAO_I2C_SCL: J9.2, J10.2, J11.2, U2.6 (PA9_A5_D5_SCL)
XIAO_I2C_SDA: J9.1, J10.1, J11.1, U2.5 (PA8_A4_D4_SDA)
XIAO_SPI_MISO: J12.2, J13.2, J14.2, U2.10 (PA5_A9_D9_MISO)
XIAO_SPI_MOSI: J12.1, J13.1, J14.1, U2.11 (PA6_A10_D10_MOSI)
XIAO_SPI_SCK: J12.3, J13.3, J14.3, U2.9 (PA7_A8_D8_SCK)
XIAO_UART_RX: J8.2, U2.8 (PB09_A7_D7_RX)
XIAO_UART_TX: J8.1, U2.7 (PB08_A6_D6_TX)

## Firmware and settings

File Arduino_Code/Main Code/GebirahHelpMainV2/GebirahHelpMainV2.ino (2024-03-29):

#include <mic.h>

// Include libraries
// #include "Arduino.h"
#include <mic.h>                            // Used for Microphone
#include "Wire.h"                           // Used for IMU
#include <stdio.h>                          // Used for type conversion
#include <string.h>                         // Used for using string
#include <stdlib.h>                         // Used for char string conversion
#include "LSM6DS3.h"                        // Used for IMU
#include "nrf_log.h"                        // Used for QSPI (ROM)
#include "nrf_delay.h"                      // Used for QSPI (ROM)
#include "nrfx_qspi.h"                      // Used for QSPI (ROM)
#include "sdk_config.h"                     // Used for QSPI (ROM)
#include <ArduinoBLE.h>                     // Used for Bluetooth Low Power
#include <ArduinoJson.h>                    // Used for using JSON
#include "nrf_log_ctrl.h"                   // Used for QSPI (ROM)
#include "avr/interrupt.h"                  // Used for QSPI (ROM)
#include "app_util_platform.h"              // Used for QSPI (ROM)
#include "nrf_log_default_backends.h"       // Used for QSPI (ROM)
#include "NRF52_MBED_TimerInterrupt.h"
#if defined(WIO_TERMINAL)                   
#include "processing/filters.h"             // Used for Microphone (PDM) Sampling
#endif

// ===== Buzzer Settings =====//
unsigned long beepTimer = 0;
uint8_t BuzzerPin       = 9;
bool BuzzerState        = false;

// ===== LED Settings ===== //
String statusForLED         = "";
uint8_t LED_BLE             = 3;
uint8_t LED_FIRST_BTN       = 5;
uint8_t LED_SECON_BTN       = 4;
unsigned long LEDTimer      = 0;
unsigned long SideLEDTimer  = 0;
bool SideLEDState           = false;
bool LEDToReset             = false;

// ===== QSPI Settings ===== //
#define QSPI_STD_CMD_WRSR   0x01
#define QSPI_STD_CMD_RSTEN  0x66
#define QSPI_STD_CMD_RST    0x99
#define QSPI_DPM_ENTER      0x0003 // 3 x 256 x 62.5ns = 48ms
#define QSPI_DPM_EXIT       0x0003

// ===== Flash Memory Settings ===== //
static nrfx_qspi_config_t           QSPIConfig;
static nrf_qspi_cinstr_conf_t       QSPICinstr_cfg;
// Setup for the SEEED XIAO BLE - nRF52840
static uint32_t *QSPI_Status_Ptr    = (uint32_t *)0x40029604;
// Alter this to create larger read writes, 64Kb is the size of the Erase
static const uint32_t MemToUse      = 64 * 1024;
static bool QSPIWait                = false;
// Usable size = 64Kb, where 1 character = 2 byte. Therefore total usable size = 32768 Characters
// 16bit used as that is what this memory is going to be used for
static uint16_t pBuf[MemToUse / 2]  = {0};
static uint32_t *BufMem             = (uint32_t *)&pBuf;

// ===== IMU Settings ===== //
#define CONVERT_G_TO_MS2 9.80665f
LSM6DS3 myIMU(I2C_MODE, 0x6A);      // I2C device address 0x6A
const int IMUBufferSize1            = 10;
float IMUVal[IMUBufferSize1][6]     = {{0},{0}};
const int IMUBufferSize2            = 2;
float IMUDiffVal[IMUBufferSize2]    = {0};
const int IMUBufferSize3            = 10;
float IMUBuffVal[IMUBufferSize3]    = {0};
uint8_t IMUFallDetectedBlinkRate    = 500;
bool IMUFallDetectedLEDLight        = false;
bool IMUFallDetected                = false;
bool IMUFallDetectedSent            = false;
unsigned long IMUBlinkTimer         = 0;

// ===== PDM Settings ===== //
#if defined(WIO_TERMINAL)
#define DEBUG 1                     // Enable pin pulse during ISR  
#define SAMPLES 16000*3
#elif defined(ARDUINO_ARCH_NRF52840)
#define DEBUG 1                     // Enable pin pulse during ISR  
#define SAMPLES 1600
#endif
mic_config_t mic_config{
    .channel_cnt = 1,
    .sampling_rate = 16000,
    #if defined(WIO_TERMINAL)
    .buf_size = 320,
    .debug_pin = 10                  // Toggles each DAC ISR (if DEBUG is set to 1)
    #elif defined(ARDUINO_ARCH_NRF52840)
    .buf_size = 1600,
    .debug_pin = 10
    // .debug_pin = LED_BUILTIN        // Toggles each DAC ISR (if DEBUG is set to 1)
    #endif
};
#if defined(WIO_TERMINAL)
DMA_ADC_Class Mic(&mic_config);
#elif defined(ARDUINO_ARCH_NRF52840)
NRF52840_ADC_Class Mic(&mic_config);
#endif
int8_t recording_buf[SAMPLES];
volatile uint8_t recording = 0;
volatile static bool record_ready = false;
volatile static bool stop_record = false;
#if defined(WIO_TERMINAL)
FilterBuHp filter;
#endif

// ===== Battery Settings ===== //
#define VBAT_ENABLE         P0_14  // 
#define BAT_HIGH_CHARGE     22  // HIGH for 50mA, LOW for 100mA
#define BAT_CHARGE_STATE    23  // LOW for charging, HIGH not charging
#define ADC_Vref            3.3
#define Voltage_Div_Num     1510.0
#define Voltage_Div_Den     510.0
#define Voltage_Div_Offset  60.3
const int sizeOfFilter          = 10;
uint8_t chargeState             = 0;
unsigned long batteryReadTime   = 0;
int     filterCnt               = 0;
float   pastBattVoltage[sizeOfFilter] = {0};
float   BatteryVoltage          = 0;
// bool    BatterySoftLimit    = true;
bool    BatteryReadingRdy       = false;

// // ===== Battery Kalman Filter ===== //
// double estBatteryVal    = 0.0;   // x - Initial Guess
// double estBatteryF      = 1.0;   // F - Only 1 Sensor
// double estBatteryH      = 1.0;   // H - Only 1 Measurement Value
// double estBatteryQ      = 0.1;          // Q - Near Calculated Value?
// double estBatteryR      = 0.00001;      // R - Near Computation
// double estBatteryKal    = 0.0;   // K
// double estBatteryP      = 1.0;   // P

// ===== Device Button Settings ===== //
uint8_t FirstBtnPin     = 0;
bool FirstBtnStatus     = false;
bool FirstBtnStatusSent = false;
bool FirstBtnFirstPress = false;
bool FirstBtnRlsePress  = false;
unsigned long FirstBtnTimer      = 0;
uint8_t SeconBtnPin     = 1;
bool SeconBtnStatus     = false;
bool SeconBtnStatusSent = false;
bool SeconBtnFirstPress = false;
bool SeconBtnRlsePress  = false;
unsigned long SeconBtnTimer      = 0;
uint8_t ThirdBtnPin     = 2;
bool ThirdBtnStatus     = false;
bool ThirdBtnFirstPress = false;
bool ThirdBtnRlseStatus = false;
unsigned long ThirdBtnTimer      = 0;

// ===== Other Settings ===== //
DynamicJsonDocument jsonData(MemToUse);
uint32_t Error_Code;
uint32_t NoOfEmergencyContact   = JSON_ARRAY_SIZE(10);
bool resetDevice                = false;
bool bluetoothConnected         = false;
bool bluetoothAuthenticated     = false;
bool bluetoothAuthenticated2    = false;
bool TokenModifyToken           = false;
bool resendSOS                  = false;
bool FirstBtnTriggered          = false;
bool SeconBtnTriggered          = false;
unsigned long BLETimer          = millis();
unsigned long sysAdminTimer     = millis();
unsigned long resendSOSTimer    = millis();

// ===== Modifiable Settings ===== //
bool AdminMode                  = false;
// bool fastCharging               = true;
// bool returnPercentage           = true;
float lowerAccelTresh           = 3.5;
uint16_t Fall_Detected          = 0;
uint16_t Debug_Status           = 0;
uint16_t sysAdmin_Time_Out      = 60*60*1000;
uint16_t Bluetooth_Time_Out     = 30*1000;
uint16_t Modify_Token_Time_Out  = 30*1000;
uint8_t  Resend_SOS_Time_Out    = 30*1000;

// ===== Bluetooh Settings ===== //
// UUID for Alert Notification Service
BLEService myService("00001811-0000-1000-8000-00805F9B34E0");
// Set BLE to read and write (When phone is unlocked), and notify (when phone is on locked)
BLEStringCharacteristic BLESAuthNum("00001811-0000-1000-8000-00805F9B34F0", BLERead | BLEWrite | BLENotify, 100);
BLEStringCharacteristic EmergencyNo("00001811-0000-1000-8000-00805F9B34F1", BLERead | BLEWrite | BLENotify, 100);
BLEStringCharacteristic getPDMSmple("00001811-0000-1000-8000-00805F9B34F2", BLERead | BLEWrite | BLENotify, 25);
BLEStringCharacteristic getDvStatus("00001811-0000-1000-8000-00805F9B34F4", BLERead | BLEWrite | BLENotify, 25);
BLEStringCharacteristic DeviceToken("00001811-0000-1000-8000-00805F9B34F5", BLERead | BLEWrite | BLENotify, 100);
BLEStringCharacteristic BtnCodeSend("00001811-0000-1000-8000-00805F9B34F6", BLERead | BLENotify, 100);
BLEStringCharacteristic BatteryStat("00001811-0000-1000-8000-00805F9B34F7", BLERead | BLENotify, 100);
BLEStringCharacteristic BatCharStat("00001811-0000-1000-8000-00805F9B34F8", BLERead | BLENotify, 100);
BLEStringCharacteristic AdminComman("00001811-0000-1000-8000-00805F9B34F9", BLERead | BLEWrite | BLENotify, 100);
BLEStringCharacteristic BleRSSIValu("00001811-0000-1000-8000-00805F9B34FA", BLERead | BLENotify, 100);

BLECharacteristic       PDMsMicRecs("00001811-0000-1000-8000-00805F9B34F3", BLERead | BLENotify , mic_config.buf_size);
const int sizeOfRSSIFilter              = 10;
int filterCntRSSI                       = 0;
float pastRSSIValue[sizeOfRSSIFilter]   = {0};

void setup()
{
    // Begin serial communication and wait for serial communicationMic
    // Initialise LED pin
    initLED();
    // Turn on all LED
    toggleLED(true);
    Serial.begin(9600);
    // Configure the data receive callback
    if (Debug_Status != 0)
    {
        while (!Serial);
    }
    // Set battery read (Test after battery is soldered)
    // pinMode(BAT_READ, OUTPUT);
    // digitalWrite(BAT_READ, LOW);
    // Print starting message
    if (Debug_Status != 0)
    {
        Serial.println("Starting Device...");
        Serial.println("Debugging Mode:" + String(Debug_Status));
    }
    // Initialise ROM
    QSPIInit();
    // Read from memory and initialise device
    // Else overwrite with default
    QSPIMemoryCheck();
    // Initialise Buzzer's Pin
    initBuzzer();
    // Initialise Battery's Pin
    initBattery();
    // Setup Microphone (PDM)
    MICInit1();
    // Set Battery current
    pinMode(P0_13, OUTPUT);
    // Check for IMU Status
    IMUInit();

    // Startup Microphone (PDM)
    MICInit2();
    // Setup and Startup BLE
    BLEInit();
    if (Debug_Status != 0)
    {
        Serial.println("Device finish setting up...");
    }
    // Turn off all LED
    toggleLED(false);
    statusForLED = "completeSetup";
}

void loop()
{
    readAllPins();
    bluetoothFunction();
    IMUFunction();
    if (resetDevice)
    {
        resetMemory();
        resetDevice = false;
    }
    runLED();
    runBattery();
    soundBuzzer();
    resetDeviceFunc();
}

static void readAllPins()
{
    debounceLatch(FirstBtnPin, &FirstBtnStatus, &FirstBtnFirstPress, &FirstBtnRlsePress, &FirstBtnTimer, &FirstBtnStatusSent);
    debounceLatch(SeconBtnPin, &SeconBtnStatus, &SeconBtnFirstPress, &SeconBtnRlsePress, &SeconBtnTimer, &SeconBtnStatusSent);
    debounce(ThirdBtnPin, &ThirdBtnStatus, &ThirdBtnFirstPress, &ThirdBtnRlseStatus, &ThirdBtnTimer);
}

static void resetDeviceFunc()
{
    if (ThirdBtnStatus)
    {
        resetMemory();
        ThirdBtnStatus = false;
    }
}

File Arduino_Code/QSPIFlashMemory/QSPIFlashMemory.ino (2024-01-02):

#include <stdio.h>
#include <string.h>
#include <stdlib.h>
#include "nrfx_qspi.h"
#include "app_util_platform.h"
#include "nrf_log.h"
#include "nrf_log_ctrl.h"
#include "nrf_log_default_backends.h"
#include "sdk_config.h"
#include "nrf_delay.h"
#include "avr/interrupt.h"

// QSPI Settings
#define QSPI_STD_CMD_WRSR 0x01
#define QSPI_STD_CMD_RSTEN 0x66
#define QSPI_STD_CMD_RST 0x99
#define QSPI_DPM_ENTER 0x0003  // 3 x 256 x 62.5ns = 48ms
#define QSPI_DPM_EXIT 0x0003

static uint32_t *QSPI_Status_Ptr = (uint32_t *)0x40029604;  // Setup for the SEEED XIAO BLE - nRF52840
static nrfx_qspi_config_t QSPIConfig;
static nrf_qspi_cinstr_conf_t QSPICinstr_cfg;
// Alter this to create larger read writes, 64Kb is the size of the Erase
static const uint32_t MemToUse = 64 * 1024;
static bool Debug_On = true;
// Usable size = 64Kb, where 1 character = 2 byte. Therefore total usable size = 32768 Characters
// 16bit used as that is what this memory is going to be used for
static uint16_t pBuf[MemToUse / 2] = { 0 };  
static uint16_t dBuf[MemToUse / 2] = { 'S', 'i', 'n', ' ', 'k', 'i', 'a', 't', ',', '1', '6' };
static uint32_t *BufMem = (uint32_t *)&pBuf;
static bool QSPIWait = false;
// QSPI Settings Complete

static void qspi_handler(nrfx_qspi_evt_t event, void *p_context) {
  // UNUSED_PARAMETER(p_context);
  // Serial.println("QSPI Interrupt");
  // if (event == NRFX_QSPI_EVENT_DONE) {
  //   QSPI_HasFinished = true;
  // }
}

static void QSPI_Status(char ASender[]) {  // Prints the QSPI Status
    Serial.print("(");
    Serial.print(ASender);
    Serial.print(") QSPI is busy/idle ... Result = ");
    Serial.println(nrfx_qspi_mem_busy_check() & 8);
    Serial.print("(");
    Serial.print(ASender);
    Serial.print(") QSPI Status flag = 0x");
    Serial.print(NRF_QSPI->STATUS, HEX);
    Serial.print(" (from NRF_QSPI) or 0x");
    Serial.print(*QSPI_Status_Ptr, HEX);
    Serial.println(" (from *QSPI_Status_Ptr)");
}

static void QSPI_PrintData(uint16_t *AnAddress, uint32_t AnAmount) {
    uint32_t i;

    Serial.print("Data :");
    for (i = 0; i < AnAmount; i++) {
        Serial.print(" 0x");
        Serial.print(*(AnAddress + i), HEX);
    }
    Serial.println("");
}

static nrfx_err_t QSPI_IsReady() {
    if (((*QSPI_Status_Ptr & 8) == 8) && (*QSPI_Status_Ptr & 0x01000000) == 0) {
        return NRFX_SUCCESS;
    } else {
        return NRFX_ERROR_BUSY;
    }
}

static nrfx_err_t QSPI_WaitForReady() {
    while (QSPI_IsReady() == NRFX_ERROR_BUSY) {
        if (Debug_On) {
        Serial.print("*QSPI_Status_Ptr & 8 = ");
        Serial.print(*QSPI_Status_Ptr & 8);
        Serial.print(", *QSPI_Status_Ptr & 0x01000000 = 0x");
        Serial.println(*QSPI_Status_Ptr & 0x01000000, HEX);
        QSPI_Status("QSPI_WaitForReady");
        }
    }
    return NRFX_SUCCESS;
}

static nrfx_err_t QSPI_Initialise() {  // Initialises the QSPI and NRF LOG
    uint32_t Error_Code;

    NRF_LOG_INIT(NULL);  // Initialise the NRF Log
    NRF_LOG_DEFAULT_BACKENDS_INIT();
    // QSPI Config
    QSPIConfig.xip_offset = NRFX_QSPI_CONFIG_XIP_OFFSET;
    QSPIConfig.pins = {
        // Setup for the SEEED XIAO BLE - nRF52840
        .sck_pin = 21,
        .csn_pin = 25,
        .io0_pin = 20,
        .io1_pin = 24,
        .io2_pin = 22,
        .io3_pin = 23,
    };
    QSPIConfig.irq_priority = (uint8_t)NRFX_QSPI_CONFIG_IRQ_PRIORITY;
    QSPIConfig.prot_if = {
        // .readoc     = (nrf_qspi_readoc_t)NRFX_QSPI_CONFIG_READOC,
        .readoc = (nrf_qspi_readoc_t)NRF_QSPI_READOC_READ4O,
        // .writeoc    = (nrf_qspi_writeoc_t)NRFX_QSPI_CONFIG_WRITEOC,
        .writeoc = (nrf_qspi_writeoc_t)NRF_QSPI_WRITEOC_PP4O,
        .addrmode = (nrf_qspi_addrmode_t)NRFX_QSPI_CONFIG_ADDRMODE,
        .dpmconfig = false,
    };
    QSPIConfig.phy_if.sck_freq = (nrf_qspi_frequency_t)NRF_QSPI_FREQ_32MDIV1;  // I had to do it this way as it complained about nrf_qspi_phy_conf_t not being visible
    // QSPIConfig.phy_if.sck_freq   = (nrf_qspi_frequency_t)NRFX_QSPI_CONFIG_FREQUENCY;
    QSPIConfig.phy_if.spi_mode = (nrf_qspi_spi_mode_t)NRFX_QSPI_CONFIG_MODE;
    QSPIConfig.phy_if.dpmen = false;
    // QSPI Config Complete
    // Setup QSPI to allow for DPM but with it turned off
    QSPIConfig.prot_if.dpmconfig = true;
    NRF_QSPI->DPMDUR = (QSPI_DPM_ENTER << 16) | QSPI_DPM_EXIT;  // Found this on the Nordic Q&A pages, Sets the Deep power-down mode timer
    Error_Code = 1;
    while (Error_Code != 0) {
        Error_Code = nrfx_qspi_init(&QSPIConfig, NULL, NULL);
        if (Error_Code != NRFX_SUCCESS) {
        if (Debug_On) {
            Serial.print("(QSPI_Initialise) nrfx_qspi_init returned : ");
            Serial.println(Error_Code);
        }
        } else {
        if (Debug_On) {
            Serial.println("(QSPI_Initialise) nrfx_qspi_init successful");
        }
        }
    }
    QSPI_Status("QSPI_Initialise (Before QSIP_Configure_Memory)");
    QSIP_Configure_Memory();
    if (Debug_On) {
        Serial.println("(QSPI_Initialise) Wait for QSPI to be ready ...");
    }
    NRF_QSPI->TASKS_ACTIVATE = 1;
    QSPI_WaitForReady();
    if (Debug_On) {
        Serial.println("(QSPI_Initialise) QSPI is ready");
    }
    return QSPI_IsReady();
}

static void QSPI_Erase(uint32_t AStartAddress) {
    uint32_t TimeTaken;
    bool QSPIReady = false;
    bool AlreadyPrinted = false;

    if (Debug_On) {
        Serial.println("(QSPI_Erase) Erasing memory");
    }
    while (!QSPIReady) {
        if (QSPI_IsReady() != NRFX_SUCCESS) {
            if (!AlreadyPrinted) {
                QSPI_Status("QSPI_Erase (Waiting)");
                AlreadyPrinted = true;
            }
        } else {
            QSPIReady = true;
            QSPI_Status("QSPI_Erase (Waiting Loop Breakout)");
        }
    }
    if (Debug_On) {
        QSPI_Status("QSPI_Erase (Finished Waiting)");
        TimeTaken = millis();
    }
    if (nrfx_qspi_erase(NRF_QSPI_ERASE_LEN_64KB, AStartAddress) != NRFX_SUCCESS) {
        if (Debug_On) {
        Serial.print("(QSPI_Initialise_Page) QSPI Address 0x");
        Serial.print(AStartAddress, HEX);
        Serial.println(" failed to erase!");
        }
    } else {
        if (Debug_On) {
        TimeTaken = millis() - TimeTaken;
        Serial.print("(QSPI_Initialise_Page) QSPI took ");
        Serial.print(TimeTaken);
        Serial.println("ms to erase a 64Kb page");
        }
    }
}
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

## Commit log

2023-11-09 Initialise schematic
    [GSM_GPS.kicad_pcb, GSM_GPS.kicad_sch, SIM8051-6-0-14-00-X-REVD.step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]
2023-11-12 Update full schematic
    [GGBLA.01.A.step, GSM_GPS.csv, GSM_GPS.kicad_pcb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]
2023-11-13 Update new schematic
    [ACAG0301-1575-T.step, GSM_GPS.csv, GSM_GPS.kicad_sch]
2023-12-01 Upload Test Code
    [GSM_GPS.csv]
2024-01-02 Update Repo with Main Hardware code and IMU Data collection code
2024-02-02 Added button with debouncing and fix MIC streaming
    [GebirahHelpBluetooth.ino, GebirahHelpMainV2.ino, GebirahHelpMicrophone.ino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]
2024-02-06 Update IMUlogging with run time
2024-02-06 Add Battery Reading
2024-02-07 Update battery offset and IMU Test
2024-02-07 add kalman filter and LED status
2024-02-15 add system admin and mean filter
2024-02-15 Added device reset, sysadmin reset and battery limit unbound view
    [GebirahHelpBattery.ino, GebirahHelpBluetooth.ino, GebirahHelpMainV2.ino]
2024-02-21 Change battery's lower bound voltage
2024-02-23 Update some IMU findings
2024-02-28 Update Arduino Code with treshold for fall detection
2024-03-06 Update switched code with latch debounce
2024-03-07 Update Buzzer and LED blink
    [Buzzers.ino, GebirahHelpMainV2.ino, StatusLED.ino]
2024-03-21 Add Battery Low and Charging Indicator, Add Active Buzzer Beep
    [Buzzers.ino, GebirahHelpIMU.ino, GebirahHelpMainV2.ino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]
2024-03-29 Add Logistic regression training
    [cleaned_exported_data2.csv, relabelledTrimmed2.csv]
2024-03-29 restructure file
    [ACAG0301-1575-T.step, GGBLA.01.A.step, GSM_GPS.csv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]
2024-03-31 Update Data
    [cleaned_exported_data2.csv, exported_data_2.csv, exported_data_4.csv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]
